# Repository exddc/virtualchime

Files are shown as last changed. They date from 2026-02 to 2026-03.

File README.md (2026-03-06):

# Virtual Chime Open Smart Doorbell System

Virtual Chime is an open source smart doorbell system built for people who want control over their home security without sacrificing privacy or design. Instead of trusting your doorbell data to cloud services, everything runs locally on hardware you own.

The system is designed to be a simple and affordable alternative to expensive designer doorbells. There should not be a compromise between security, privacy and good design. Virtual Chime aims to be as beautiful as designer doorbells, as secure as the most expensive security systems, and as private as your own home.

Read more about the rewrite process in my [blog post](https://timoweiss.me/blog/rewriting-virtual-chime).

## Current Status: Full Rewrite

This repository is being actively rewritten from scratch. After 1.5 years of running the original system in production, lessons learned have led to a completely new architecture. The old code is in the `old` branch and will be removed once the rewrite is complete.

## The New Architecture

The rewrite focuses on:

- **Compiled C++ services** instead of Python runtime on-device for reliability and speed
- **Explicit separation** between product runtime and configuration runtime
- **Custom minimal Linux image** tailored for fast boot and appliance-grade reliability
- **Single repository** containing OS, application, Web UI, scripts, and hardware assets
- **OTA updates** for firmware (A/B rootfs slots) and application services

## Products

The Virtual Chime family consists of multiple products working together:

### Chime (Speaker Box)

The first rewritten product - a purpose-built IoT speaker that plays doorbell sounds when triggered over MQTT. It runs on a custom ~300MB Linux image built with Buildroot, boots in under 5 seconds, and provides a secure web interface for configuration.

**Hardware:** Raspberry Pi Zero W, MAX98357A I2S amplifier, LSM-104F-8 speaker, 3D-printed enclosure

See [Chime README](chime/README.md) for detailed technical specifications.

### Bell (Doorbell) - In Progress

The actual doorbell unit with camera, button, and MQTT integration. Currently in planning stages, will follow the same architecture as the chime.

## Repository Structure

```
├── buildroot/          # Buildroot configuration for custom Linux images
├── chime/              # C++ source for chime audio/MQTT service
├── chime-webd/         # C++ source for HTTPS configuration daemon
├── webui/              # Svelte-based web configuration interface
├── scripts/            # Build and deployment automation
├── hardware/           # 3D models and hardware designs
└── docs/               # Documentation and blog drafts
```

## Documentation

- [Chime README](chime/README.md) - Technical overview of the chime product
- [Buildroot README](buildroot/README.md) - Image build, flash, and OTA workflow details
- [Hardware README](hardware/chime/README.md) - Detailed write-up of the hardware designs

## License

This project is licensed under the [MIT License](LICENSE).

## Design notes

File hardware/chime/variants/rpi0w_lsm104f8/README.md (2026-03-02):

# Raspberry Pi Zero W LSM-104F-8

## Description

This variant is built for the Raspberry Pi Zero W and uses the LSM-104F-8 speaker in combination with the MAX98357A amplifier.

## BOM

- 1x Raspberry Pi Zero W
- 1x LSM-104F-8 speaker
- 1x MAX98357A amplifier
- 4x M4x5mm screws
- 4x M2x4mm screws
- 1x 3D printed body
- 1x 3D printed face cover

## Assembly

1. Attach the MAX98357A amplifier to the speaker with the + and - terminals facing the correct way.
2. Attach the MAX98357A amplifier to the Raspberry Pi Zero W to the GPIO pins.
3. Fix the Raspberry Pi Zero W to the enclosure with the 4x M2x4mm screws. Check that the PWR_IN USB port is accessible from the outside of the enclosure.
4. Screw the Speaker to the enclosure with the 4x M4x5mm screws.
5. Press the face cover onto the body.

## Wiring

| Raspberry Pi Zero W | MAX98357A |
|---|---|
| Pin 4 (5V) | VIN |
| Pin 6 (GND) | GND |
| Pin 12 (GPIO18) | BCLK |
| Pin 35 (GPIO19) | LRC |
| Pin 40 (GPIO21) | DIN |
| 5V | SD |

## Volume control note

MAX98357A does not expose runtime digital volume control over I2S. On common breakout boards, gain is selected by the SD/GAIN pin strapping and is therefore hardware-defined unless that pin is connected to a controllable GPIO. In this project, volume is handled in software via ALSA mixer level before playback.

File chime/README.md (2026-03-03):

# Chime Service

`chime` is a minimal MQTT-to-audio daemon for the Raspberry Pi Zero W.
`chime-webd` is a lightweight HTTPS control-plane daemon for web configuration APIs/UI.

Operational runbook: `RELIABILITY_RUNBOOK.md`.

## Local CI Checks

Run the same checks as GitHub chime CI from the repo root:

```bash
./scripts/chime_ci.sh
```

Useful options:
- `./scripts/chime_ci.sh --fix-format` to apply `clang-format` to the checked files.
- `CHIME_CI_SCOPE=changed CHIME_CI_BASE_REF=origin/main ./scripts/chime_ci.sh` to lint/format only files changed from a base ref.

For repository-wide formatting/lint checks (C/C++ + webui Biome), run:

```bash
./scripts/lint_format_ci.sh
```

## Runtime Behavior

1. Loads config from `/etc/chime.conf` (or `$CHIME_CONFIG`).
2. Connects to MQTT broker and subscribes to configured topics.
3. When a message arrives on `ring_topic`, plays `sound_path` using `aplay`.
4. Publishes `heartbeat_topic` every `heartbeat_interval` seconds.
5. Automatically reconnects to MQTT after disconnect or loop errors.

## Web Platform (`chime-webd`)

- Serves HTTPS UI/API on port `8443`.
- Hosts current v1 endpoints:
  - `GET /`
  - `GET /api/v1/config/core`
  - `POST /api/v1/config/core`
  - `GET /api/v1/wifi/scan`
  - `GET /api/v1/mqtt/topics` (observed MQTT topics for ring-topic suggestions)
- Reserves `/api/v1/system/*`, `/api/v1/device/*`, and `/api/v1/diagnostics/*` for future API expansion (`501` responses in v1).
- Uses self-signed TLS cert/key at:
  - `/etc/chime-web/tls/cert.pem`
  - `/etc/chime-web/tls/key.pem`
- Optional static UI override:
  - Set `CHIME_WEBD_UI_DIST_DIR` to serve built web assets (for example Svelte
    `dist/`) instead of the embedded fallback UI.
- Runs as a separate process from `chime` for ring-path reliability isolation.

## Reliability Logging

All logs go to `/var/log/chime.log` through the init supervisor (`S99chime`).

The daemon now logs:
- Service lifecycle (`service starting`, config loaded, shutdown reason, `service stopped`)
- MQTT lifecycle (connect attempts, successful connection, subscribe results, disconnects, loop errors, reconnect attempts, heartbeat publish success/fail)
- Message traffic (topic, qos, retain, payload length and sanitized payload)
- Ring handling (`ring received`, audio playback start, playback completion/failure, dedup when already playing)
- WiFi state (`operstate` and `carrier`) and changes/dropouts for the configured interface
- Periodic health summary every 60 seconds (message counters, reconnect counters, connection state)

## Config Keys

See `/etc/chime.conf` for defaults.

Daemon keys:
- `mqtt_host`, `mqtt_port`, `mqtt_client_id`
- `mqtt_username`, `mqtt_password` (optional broker auth)
- `mqtt_tls_enabled`, `mqtt_tls_validate_certificate`
- `mqtt_tls_ca_file`, `mqtt_tls_cert_file`, `mqtt_tls_key_file`
- `mqtt_topics` (comma-separated)
- `mqtt_subscribe_qos` (0-2)
- `heartbeat_interval` (0 disables)
- `heartbeat_topic`
- `ring_topic`
  - Supports MQTT topic filters (`+` and `#`) for matching incoming message topics
- `sound_path`
- `volume_bell` (0-100, bell/ring events)
- `volume_notifications` (0-100, startup/notification category)
- `volume_other` (0-100, fallback category)
- `audio_enabled`
- `wifi_interface`
- `wifi_check_interval` (0 disables WiFi state checks)

Init-service keys (used by `S41timesync` and `S99chime`):
- `ntp_servers` (comma-separated)
- `time_http_urls` (comma-separated HTTP URLs used as fallback Date source)
- `time_sync_retries`, `time_sync_retry_delay`, `time_sync_interval`
- `log_max_bytes`, `log_rotate_keep`, `log_rotate_check_interval`

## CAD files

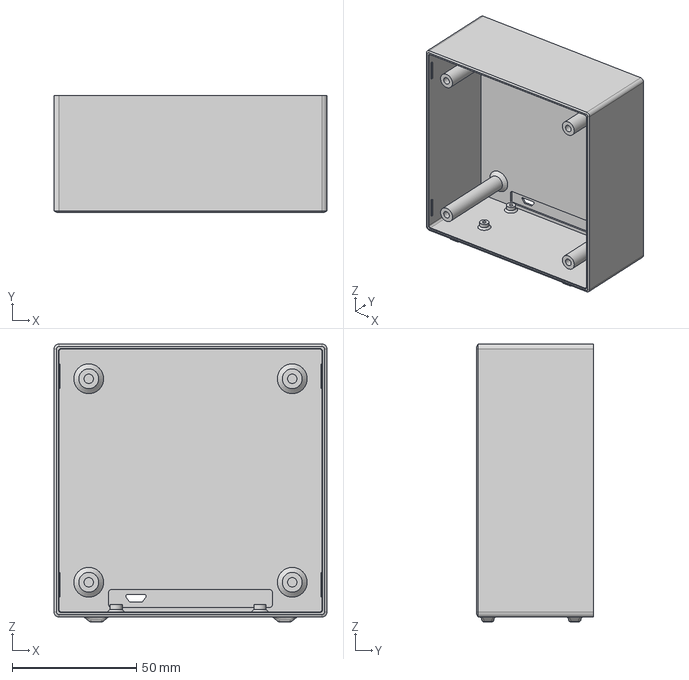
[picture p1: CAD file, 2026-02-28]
hardware/chime/cad/fusion/exports/Body.step
110.0 x 47.0 x 112.0 mm

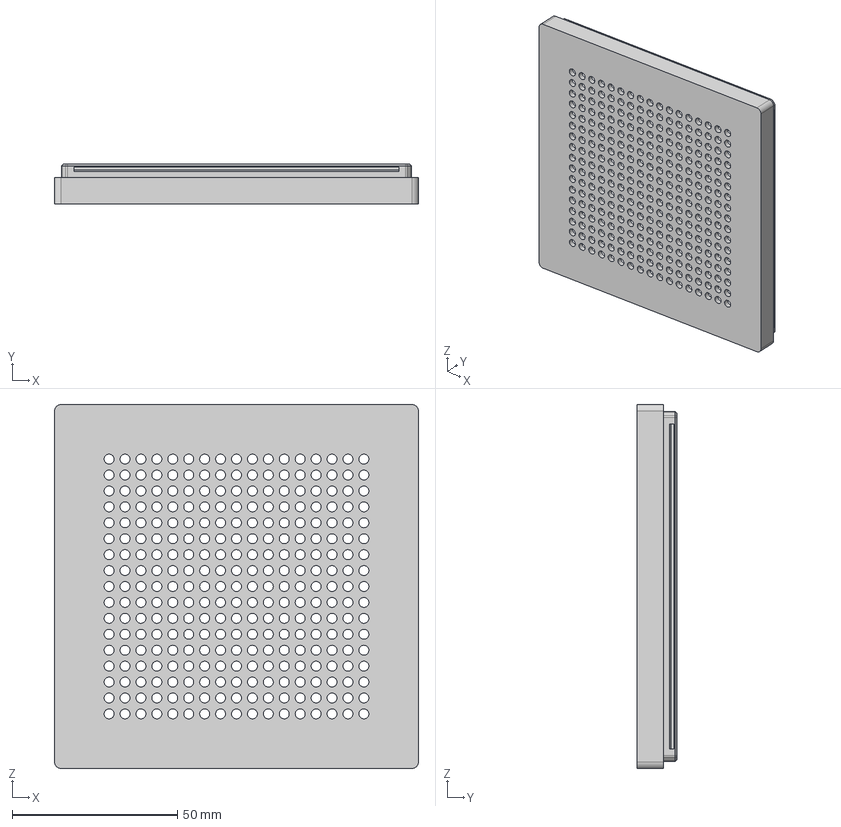
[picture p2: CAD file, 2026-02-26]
hardware/chime/cad/fusion/exports/Front_Cover.step
110.0 x 12.0 x 110.0 mm

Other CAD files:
hardware/chime/variants/rpi0w_lsm104f8/prints/Chime_Body.3mf
hardware/chime/variants/rpi0w_lsm104f8/prints/Chime_Front_Cover.3mf
hardware/chime/cad/fusion/Body.f3d
hardware/chime/cad/fusion/Front_Cover.f3d

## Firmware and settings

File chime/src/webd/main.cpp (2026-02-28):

#include <cctype>
#include <chrono>
#include <csignal>
#include <cstdlib>
#include <fstream>
#include <iostream>
#include <string>
#include <thread>
#include <utility>

#include "chime/webd_apply_manager.h"
#include "chime/webd_config_store.h"
#include "chime/webd_mdns.h"
#include "chime/webd_web_server.h"
#include "chime/webd_wifi_scan.h"
#include "vc/config/kv_config.h"
#include "vc/logging/logger.h"
#include "vc/runtime/signal_handler.h"
#include "vc/util/environment.h"

namespace {

constexpr const char *kChimeConfigPath = "/etc/chime.conf";
constexpr const char *kWpaSupplicantPath = "/etc/wpa_supplicant/wpa_supplicant.conf";
constexpr const char *kTlsCertPath = "/etc/chime-web/tls/cert.pem";
constexpr const char *kTlsKeyPath = "/etc/chime-web/tls/key.pem";
constexpr const char *kUiDistDir = "/usr/local/share/chime-web-ui/dist";
constexpr const char *kBindAddress = "0.0.0.0";
constexpr int kListenPort = 8443;
constexpr const char *kHostLabel = "chime";
constexpr const char *kNetworkRestartCommand = "/etc/init.d/S40network restart >/dev/null 2>&1";
constexpr const char *kChimeRestartCommand = "/etc/init.d/S99chime restart >/dev/null 2>&1";
constexpr const char *kObservedTopicsPath = "/var/lib/chime/observed_topics.txt";
constexpr const char *kRingSoundsDir = "/var/lib/chime/ring_sounds";
constexpr const char *kActiveRingSoundPath = "/usr/local/share/chime/ring.wav";

std::string EnvOrDefault(const char *key, const char *fallback) {
    const std::string value = vc::util::GetEnv(key);
    if (!value.empty()) {
        return value;
    }
    return fallback;
}

int EnvIntOrDefault(const char *key, int fallback) {
    const std::string value = vc::util::GetEnv(key);
    if (value.empty()) {
        return fallback;
    }

    char *end = nullptr;
    const long parsed = std::strtol(value.c_str(), &end, 10);
    if (end == nullptr || *end != '\0' || parsed < 1 || parsed > 65535) {
        return fallback;
    }
    return static_cast<int>(parsed);
}

bool EnvBoolOrDefault(const char *key, bool fallback) {
    const std::string value = vc::config::trim(vc::util::GetEnv(key));
    if (value.empty()) {
        return fallback;
    }
    std::string lowered;
    lowered.reserve(value.size());
    for (const char c : value) {
        lowered.push_back(static_cast<char>(std::tolower(static_cast<unsigned char>(c))));
    }
    if (lowered == "1" || lowered == "true" || lowered == "yes" || lowered == "on") {
        return true;
    }
    if (lowered == "0" || lowered == "false" || lowered == "no" || lowered == "off") {
        return false;
    }
    return fallback;
}

std::string ReadWifiInterfaceOrDefault(const std::string &path) {
    std::ifstream file(path);
    if (!file.is_open()) {
        return "wlan0";
    }

    std::string line;
    while (std::getline(file, line)) {
        const std::string trimmed = vc::config::trim(line);
        if (trimmed.empty() || trimmed[0] == '#') {
            continue;
        }
        if (trimmed.rfind("wifi_interface=", 0) == 0) {
            const std::string value = vc::config::trim(trimmed.substr(15));
            if (!value.empty()) {
                return value;
            }
        }
    }
    return "wlan0";
}

void PrintUsage(const char *program) {
    std::cout << "Usage: " << program << " [--help]\n";
    std::cout << "Environment overrides:\n";
    std::cout << "  CHIME_WEBD_CHIME_CONFIG\n";
    std::cout << "  CHIME_WEBD_WPA_SUPPLICANT\n";
    std::cout << "  CHIME_WEBD_TLS_CERT\n";
    std::cout << "  CHIME_WEBD_TLS_KEY\n";
    std::cout << "  CHIME_WEBD_BIND_ADDRESS\n";
    std::cout << "  CHIME_WEBD_PORT\n";
    std::cout << "  CHIME_WEBD_HOST_LABEL\n";
    std::cout << "  CHIME_WEBD_WIFI_INTERFACE\n";
    std::cout << "  CHIME_WEBD_NETWORK_RESTART_CMD\n";
    std::cout << "  CHIME_WEBD_CHIME_RESTART_CMD\n";
    std::cout << "  CHIME_WEBD_MDNS_ENABLED\n";
    std::cout << "  CHIME_WEBD_UI_DIST_DIR\n";
    std::cout << "  CHIME_WEBD_OBSERVED_TOPICS_PATH\n";
    std::cout << "  CHIME_WEBD_RING_SOUNDS_DIR\n";
    std::cout << "  CHIME_WEBD_ACTIVE_RING_SOUND\n";
}

} // namespace

int main(int argc, char *argv[]) {
    if (argc > 1) {
        const std::string arg = argv[1];
        if (arg == "--help" || arg == "-h") {
            PrintUsage(argv[0]);
            return 0;
        }
        std::cerr << "Unknown option: " << arg << "\n";
        PrintUsage(argv[0]);
        return 2;
    }

    std::cout.setf(std::ios::unitbuf);
    std::cerr.setf(std::ios::unitbuf);

    vc::logging::StderrLogger logger;
    vc::runtime::SignalHandler signal_handler;
    signal_handler.Install();
#if !defined(_WIN32)
    std::signal(SIGPIPE, SIG_IGN);
#endif

    const std::string chime_config_path = EnvOrDefault("CHIME_WEBD_CHIME_CONFIG", kChimeConfigPath);
    const std::string wpa_supplicant_path = EnvOrDefault("CHIME_WEBD_WPA_SUPPLICANT", kWpaSupplicantPath);
    const std::string tls_cert_path = EnvOrDefault("CHIME_WEBD_TLS_CERT", kTlsCertPath);
    const std::string tls_key_path = EnvOrDefault("CHIME_WEBD_TLS_KEY", kTlsKeyPath);
    const std::string ui_dist_dir = EnvOrDefault("CHIME_WEBD_UI_DIST_DIR", kUiDistDir);
    const std::string observed_topics_path = EnvOrDefault("CHIME_WEBD_OBSERVED_TOPICS_PATH", kObservedTopicsPath);
    const std::string ring_sounds_dir = EnvOrDefault("CHIME_WEBD_RING_SOUNDS_DIR", kRingSoundsDir);
    const std::string active_ring_sound_path = EnvOrDefault("CHIME_WEBD_ACTIVE_RING_SOUND", kActiveRingSoundPath);
    const std::string bind_address = EnvOrDefault("CHIME_WEBD_BIND_ADDRESS", kBindAddress);
    const int listen_port = EnvIntOrDefault("CHIME_WEBD_PORT", kListenPort);
    const std::string host_label = EnvOrDefault("CHIME_WEBD_HOST_LABEL", kHostLabel);
    const std::string wifi_interface_override = vc::util::GetEnv("CHIME_WEBD_WIFI_INTERFACE");
    const std::string wifi_interface =
        wifi_interface_override.empty() ? ReadWifiInterfaceOrDefault(chime_config_path) : wifi_interface_override;
    const std::string network_restart_command = EnvOrDefault("CHIME_WEBD_NETWORK_RESTART_CMD", kNetworkRestartCommand);
    const std::string chime_restart_command = EnvOrDefault("CHIME_WEBD_CHIME_RESTART_CMD", kChimeRestartCommand);
    const bool mdns_enabled = EnvBoolOrDefault("CHIME_WEBD_MDNS_ENABLED", true);

    chime::webd::ConfigStore config_store(logger, chime_config_path, wpa_supplicant_path);
    chime::webd::WifiScanner wifi_scanner(logger, wifi_interface);
    chime::webd::ApplyManager apply_manager(logger, network_restart_command, chime_restart_command);
    chime::webd::WebServer web_server(logger, config_store, wifi_scanner, apply_manager, bind_address, listen_port,
                                      tls_cert_path, tls_key_path, ui_dist_dir, observed_topics_path, ring_sounds_dir,
                                      active_ring_sound_path);
    chime::webd::MdnsResponder mdns(logger, host_label, wifi_interface);

    if (!web_server.Start()) {
        logger.Error("webd", "failed to start web server");
        return 1;
    }

    if (mdns_enabled && !mdns.Start()) {
        logger.Warn("webd", "mDNS responder failed to start");
    } else if (!mdns_enabled) {
        logger.Info("webd", "mDNS responder disabled by CHIME_WEBD_MDNS_ENABLED");
    }

    logger.Info("webd", "chime-webd started");

    while (!signal_handler.ShouldStop()) {
        std::this_thread::sleep_for(std::chrono::milliseconds(200));
    }

    mdns.Stop();
    web_server.Stop();

    logger.Info("webd", "chime-webd stopped");
    return 0;
}

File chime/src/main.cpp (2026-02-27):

#include <fstream>
#include <iostream>
#include <string>

#include "chime/audio_player.h"
#include "chime/chime_config.h"
#include "chime/chime_service.h"
#include "chime/wifi_monitor.h"
#include "vc/logging/logger.h"
#include "vc/runtime/signal_handler.h"
#include "vc/util/environment.h"

namespace {
constexpr const char* kDefaultConfigPath = "/etc/chime.conf";
constexpr const char* kReleaseFilePath = "/etc/virtualchime-release";

#ifndef CHIME_APP_VERSION
#define CHIME_APP_VERSION "dev"
#endif

#ifndef VIRTUALCHIME_OS_VERSION
#define VIRTUALCHIME_OS_VERSION "dev"
#endif

#ifndef CHIME_CONFIG_VERSION
#define CHIME_CONFIG_VERSION "dev"
#endif

#ifndef CHIME_BUILD_ID
#define CHIME_BUILD_ID "unknown"
#endif

std::string ReadReleaseValue(const std::string& key) {
  std::ifstream release_file(kReleaseFilePath);
  if (!release_file.is_open()) {
    return "";
  }

  const std::string prefix = key + "=";
  std::string line;
  while (std::getline(release_file, line)) {
    if (line.rfind(prefix, 0) == 0) {
      return line.substr(prefix.size());
    }
  }

  return "";
}

void PrintUsage(const char* program) {
  std::cout << "Usage: " << program << " [--version]\n";
}

void PrintVersion() {
  std::cout << "CHIME_APP_VERSION=" << CHIME_APP_VERSION << "\n";
  std::cout << "CHIME_BUILD_ID=" << CHIME_BUILD_ID << "\n";
  std::cout << "VIRTUALCHIME_OS_VERSION=" << VIRTUALCHIME_OS_VERSION << "\n";
  std::cout << "CHIME_CONFIG_VERSION=" << CHIME_CONFIG_VERSION << "\n";

  const std::string runtime_os_version =
      ReadReleaseValue("VIRTUALCHIME_OS_VERSION");
  if (!runtime_os_version.empty()) {
    std::cout << "RUNTIME_OS_VERSION=" << runtime_os_version << "\n";
  }

  const std::string runtime_kernel_version =
      ReadReleaseValue("LINUX_KERNEL_RELEASE");
  if (!runtime_kernel_version.empty()) {
    std::cout << "RUNTIME_KERNEL_RELEASE=" << runtime_kernel_version << "\n";
  }

  const std::string runtime_app_build_id = ReadReleaseValue("CHIME_BUILD_ID");
  if (!runtime_app_build_id.empty()) {
    std::cout << "RUNTIME_CHIME_BUILD_ID=" << runtime_app_build_id << "\n";
  }

  const std::string runtime_source_sha = ReadReleaseValue("SOURCE_GIT_SHA");
  if (!runtime_source_sha.empty()) {
    std::cout << "RUNTIME_SOURCE_GIT_SHA=" << runtime_source_sha << "\n";
  }
}
}

int main(int argc, char* argv[]) {
  if (argc > 1) {
    const std::string arg = argv[1];
    if (arg == "--version" || arg == "-v") {
      PrintVersion();
      return 0;
    }
    if (arg == "--help" || arg == "-h") {
      PrintUsage(argv[0]);
      return 0;
    }

    std::cerr << "Unknown option: " << arg << "\n";
    PrintUsage(argv[0]);
    return 2;
  }

  std::cout.setf(std::ios::unitbuf);
  std::cerr.setf(std::ios::unitbuf);

  vc::logging::StderrLogger logger;
  vc::runtime::SignalHandler signal_handler;
  signal_handler.Install();

  const std::string config_env = vc::util::GetEnv("CHIME_CONFIG");
  const std::string config_path =
      config_env.empty() ? kDefaultConfigPath : config_env;

  auto result = chime::LoadConfig(config_path);
  if (!result) {
    logger.Error("chime", result.error);
    return 1;
  }

  const std::string client_id_override = vc::util::GetEnv("CHIME_MQTT_CLIENT_ID");
  if (!client_id_override.empty()) {
    result.config.client_id = client_id_override;
    logger.Info("mqtt", "client_id override from CHIME_MQTT_CLIENT_ID");
  }

  const std::string mqtt_username_override =
      vc::util::GetEnv("CHIME_MQTT_USERNAME");
  if (!mqtt_username_override.empty()) {
    result.config.mqtt_username = mqtt_username_override;
    logger.Info("mqtt", "username override from CHIME_MQTT_USERNAME");
  }

  const std::string mqtt_password_override =
      vc::util::GetEnv("CHIME_MQTT_PASSWORD");
  if (!mqtt_password_override.empty()) {
    result.config.mqtt_password = mqtt_password_override;
    logger.Info("mqtt", "password override from CHIME_MQTT_PASSWORD");
  }

  logger.Info("chime", "loaded config from " + config_path);

  chime::AplayAudioPlayer audio_player(logger);
  chime::LinuxWifiMonitor wifi_monitor;
  chime::ChimeService service(result.config, logger, audio_player, wifi_monitor);

  return service.Run(signal_handler);
}

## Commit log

2024-06-06 added rfid and relay agent
2024-06-06 added faceplate and button 3d files
    [Button.3mf, Faceplate.3mf]
2024-06-07 updated .env sample
2024-06-07 changed camera setup
2024-06-17 updated hardware
    [Button.3mf, Button_Flush.3mf, Faceplate.3mf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]
2024-06-21 changed to socket udp stream
2024-06-21 switched to tcp socket
2024-06-24 Fixed threading
2024-06-24 added camera connection check
2024-07-04 added relay trigger buttons to dashboard
2024-08-26 moved hardware to separte repo
    [Button_Flush.3mf, Faceplate_3Parties.3mf, Nameplate_Blank.3mf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]
2024-10-11 added button testing script
2024-10-14 moved button init
2024-10-15 added stuck button detection
2024-10-16 created relay test script
2024-10-17 fixed unreliable relay control
2024-11-16 Added another button test script with gpiozero
2026-01-28 Running chime app on raspberry
2026-02-13 Chime Hardware v1
    [Body.f3d, Body.step, Chime_Body.3mf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]
2026-02-14 Better wiring table
2026-02-16 New Chime Front Cover
    [Chime_Front_Cover.3mf, Front_Cover.f3d, Front_Cover.step]
2026-02-26 feat: improved front cover lipt for better assembly
    [Chime_Front_Cover.3mf, Front_Cover.f3d, Front_Cover.step]
2026-02-26 fix: wall thickness on hook too thin
    [Chime_Front_Cover.3mf, Front_Cover.f3d, Front_Cover.step]
2026-02-27 feat: svelte webui, mqtt broker login credentials
    [main.cpp]
2026-02-28 Address ring-sound review fixes and harden upload flow
2026-02-28 Fix directory-race handling and ring-sound button preconditions
2026-02-28 feat: added champfer to connecting edge
    [Body.f3d, Body.step, Chime_Body.3mf]
2026-02-28 fix: link webd utils, deploy ui assets atomically, seed default ring sound
    [main.cpp]
2026-03-01 Validate and clamp volume values before config submission
